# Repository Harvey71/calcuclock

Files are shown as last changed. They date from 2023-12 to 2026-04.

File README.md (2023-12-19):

# CalcuClock

Inspired by a commercial product (Albertclock), I always wanted to create a similar project. The idea is, that the time is displayed as two simple math expressions, which the user has to solve in order to read the clock.
Take it as an educational mean or just a geek toy. ;-)

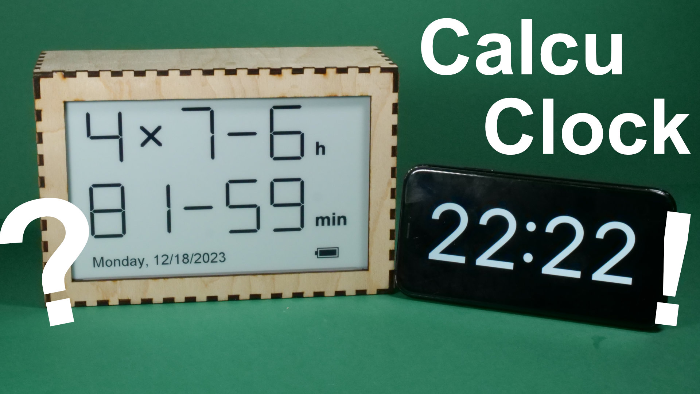
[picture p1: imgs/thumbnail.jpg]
CalcuClock


I used a Firebeetle ESP32 microcontroller board, which has a very low deep sleep current, a Wireshare 7.5 inch ePaper display and a DS3231 real time clock module. The clock is powered by a 10,000 mAh recharchable LiPo-battery, which hopefully will provide a very long duration before recharging, so you can place it anywhere you want (desk, shelf, wall) without a cable attached.

You can easily set up time and time zone by using a standard smartphone and WiFi.

You can watch the clock in action and how I made it at https://youtu.be/ywXnWx0vjIA.

## Hardware

### Part List

| Part | Link |
|---|---|
| Firebeetle ESP32 Microcontroller Board | https://www.dfrobot.com/product-1590.html |
| Waveshare E-Paper Driver HAT | https://www.waveshare.com/product/displays/e-paper/driver-boards/e-paper-driver-hat.htm |
| Waveshare 800×480, 7.5inch E-Ink raw display | https://www.waveshare.com/7.5inch-e-paper.htm |
| Makerfocus 10,000 mAh LiPo Battery | https://www.amazon.de/gp/product/B0953L98RK |
| USB-C power socket | https://www.amazon.de/gp/product/B0C6D2YS1V |
| Push Button Switch | https://www.amazon.de/gp/product/B081TZFZVS |
| DS3231 RTC module | https://www.amazon.de/gp/product/B07GZHTKCS |
| 2 x 1 MOhm resistor | |
| 1 x 100 nF capacitor | |
| 3 mm plywood | |
| Breadboard, screws, cables, spacer, pin header, etc | | 

### Microcontroller

The microcontroller board comes with a voltage divider for measuring battery voltage, but two connections have to
be bridged in order to make this divider work:

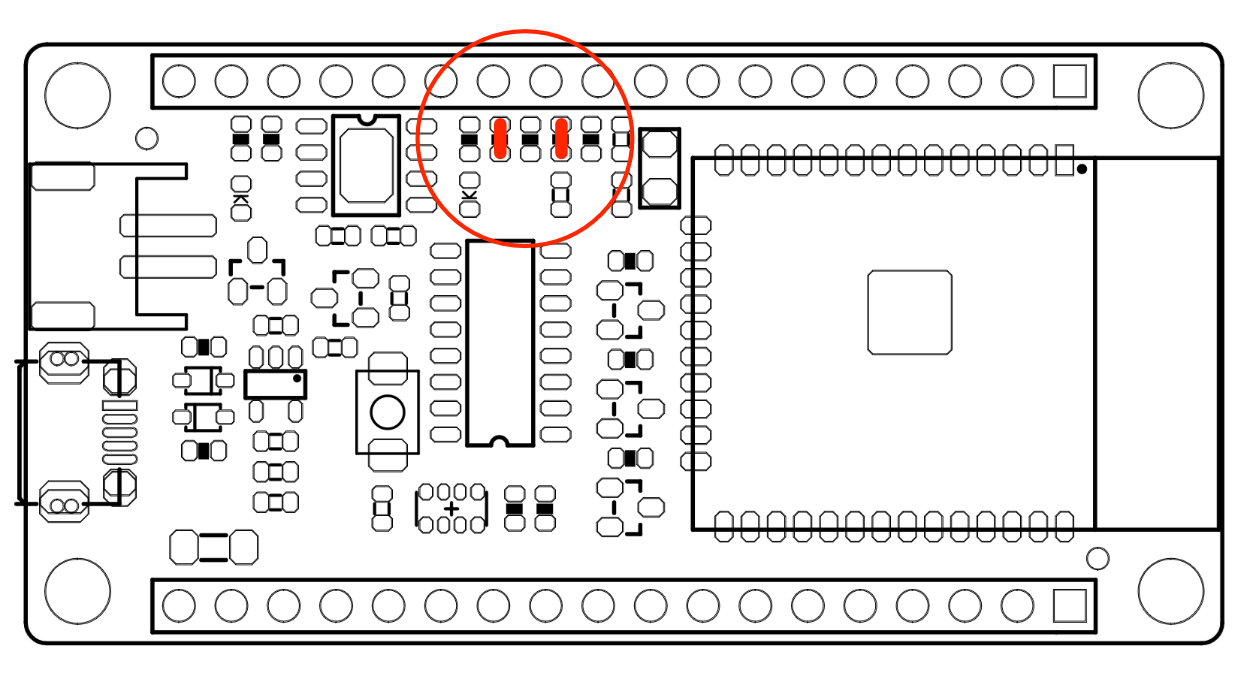
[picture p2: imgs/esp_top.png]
Firebeetle top


You could use a USB cable extension to make the USB connection accessible from outside the box, but I wanted to use a
USB-C power socket, so I had to connect it to the board directly:

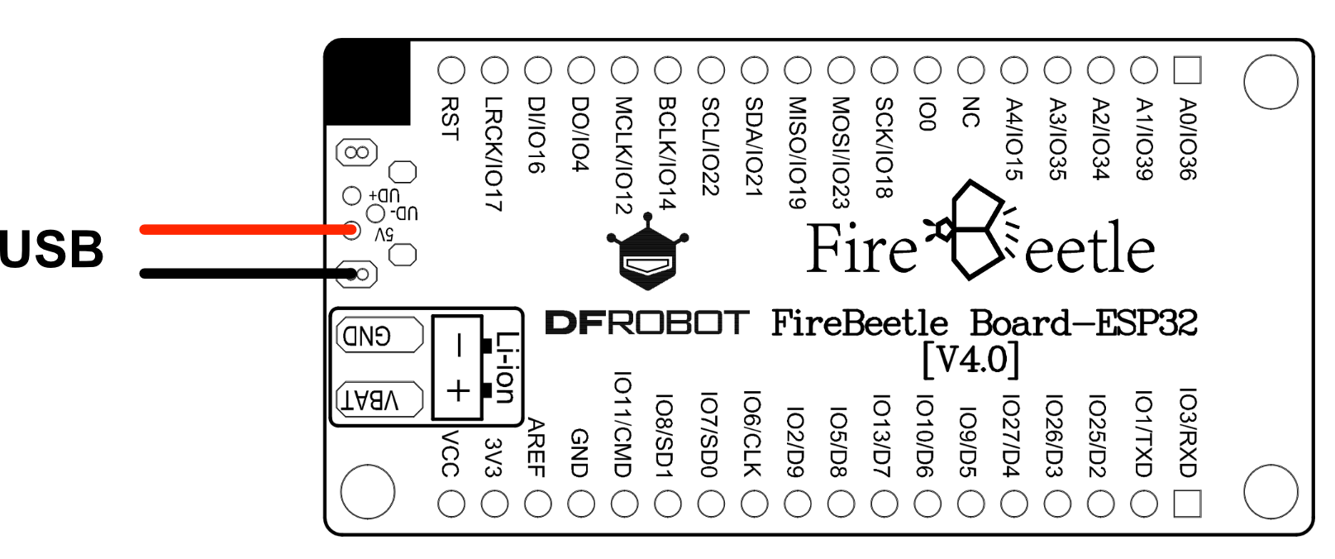
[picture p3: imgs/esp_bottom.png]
Firebeetle bottom


### Bread board

Unfortunately, the Firebeetle does not come with a USB voltage sensor. So I had to install an extra voltage divider on
my own with two 1 MOhm resistors. I used a breadboard and pin headers to connect the microcontroller, the RTC module and
the reset button. I soldered the E-Paper driver cable directly to the board:

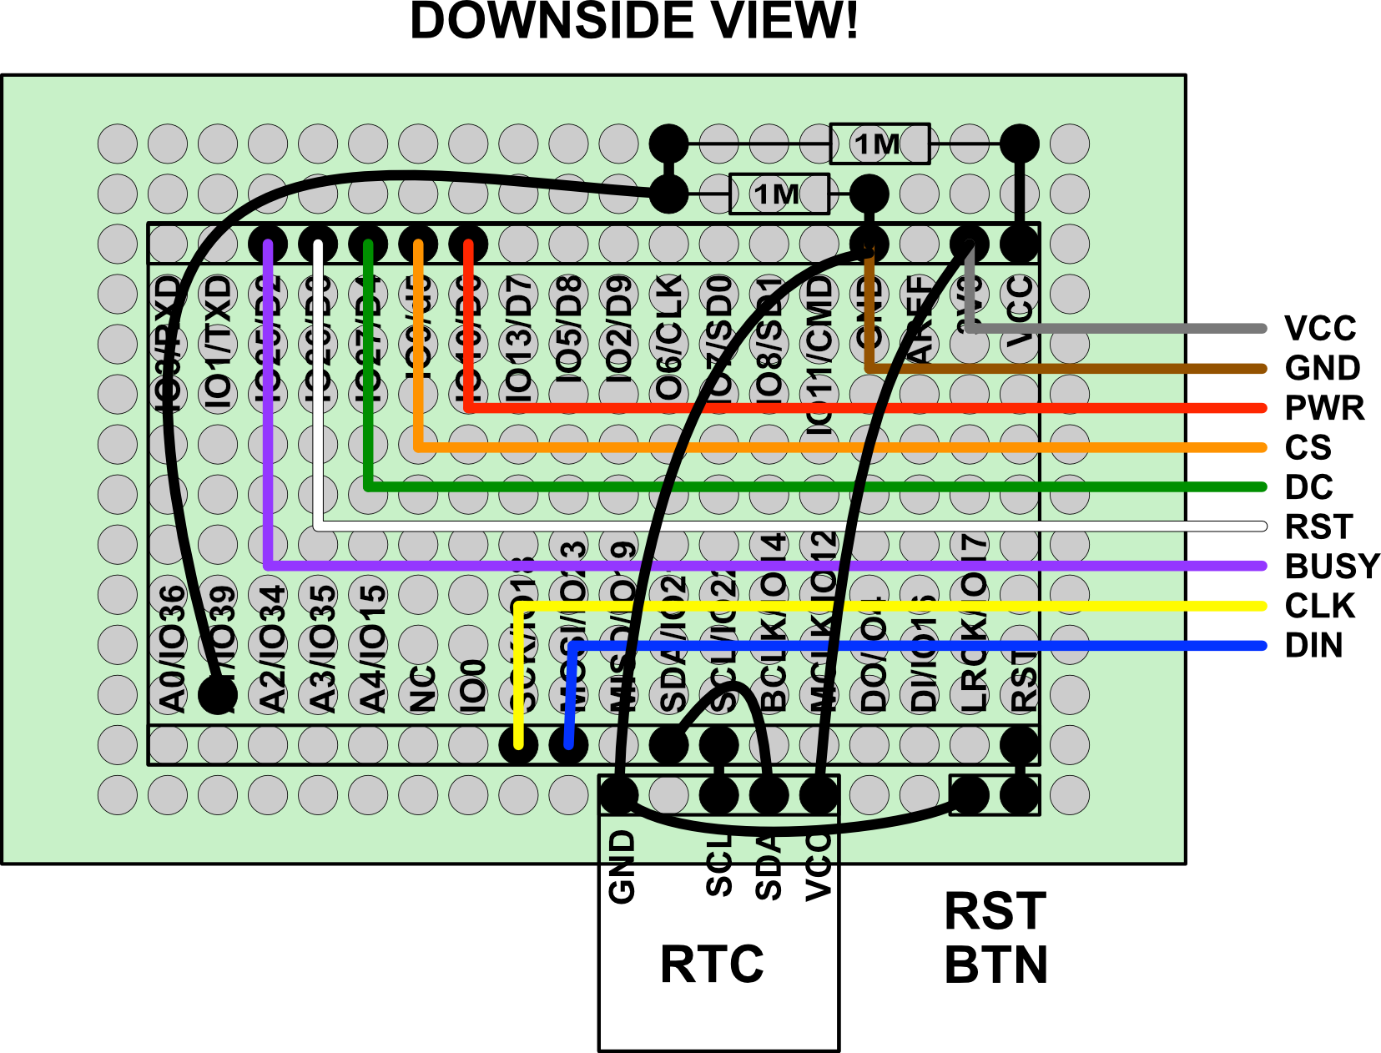
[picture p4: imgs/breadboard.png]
Breadboard


### RTC module

I had some troubles with the accuracy of the RTC module. A 100nF capacitor between GND and VCC soldered directly to 
the module helped.

### Casing

For the casing you would need a laser cutter. I used a Snapmaker A350T with 40W laser module and standard settings.
You can find the cutting blueprints as SVG files in the [box](box) directory.

box1
box2

## Software

Just install a micropython firmware on the ESP32 and copy all the files from [code](code) to the microcontroller file system.
I recommend using Thonny (https://thonny.org/) for that. Be patient, this may take a while.

The digits are pre-rendered and the math expressions are pre-calculated. You can easily change either of them using the 
Python scripts provided in the [tools](tools) directory.

## Usage

After assembling the clock (see video for that), you have to set the time, time zone and date format. For that,
the ESP32 opens a Wifi network (SID "calcuclock") and provides a simple web interface on http://192.168.4.1.
The WiFi password is generated randomly at first activation of the clock.

To make setup easy for a user with a smartphone, the clock displays two QR codes on the e-paper display - one for the 
WiFi settings and one for the URL. Just scan and execute the QR codes as displayed on the e-paper and the setup
interface will appear on your phone. Choose your settings and press "Synchronize". The current date and time will be
read automatically from your phone and sent to the clock. After that the clock will switch to regular work mode and
displays the time as math equations. The display will be updated every minute.

If you want to change the settings later on, just press the reset button on the back of the clock and it will go to
setup mode again.

## Limitations

While the time zone selection should be sufficient, I only implemented two date formats: English and German. Please feel
free to add further. Just add them to the dt_formats object in the [code/clock.py](code/clock.py) file.

I also implemented a 24h mode only. If you really want a 12h AM/PM display, you would have to modify the code.

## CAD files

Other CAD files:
box/box.dxf
box/box2.dxf

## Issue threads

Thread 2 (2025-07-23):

Bridges at microcontroller

Ra1080, 2025-07-23:
You wrote, that two connections at the microcontroller board have to be bridged in order to make the voltage divider work. As far as I could see, the bridges in the linked video differ from the ones marked in your description. Which of them is correct? Thank you for your answer.

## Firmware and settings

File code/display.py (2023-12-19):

import machine
import time
from lib.writer import writer
import framebuf
import arial_40
from array import array

class DisplayFrameBuffer(framebuf.FrameBuffer):

    def __init__(self, buf, width, height, *args, **kwargs):
        self.width = width
        self.height = height
        super().__init__(buf, width, height, *args, **kwargs)
        
class Display:

    def __init__(self):
        self.width = 800
        self.height = 480
        self.buf = bytearray(self.width * self.height // 8)
        self.fb = DisplayFrameBuffer(self.buf, self.width, self.height, framebuf.MONO_HLSB)
        self.writer = writer.Writer(self.fb, arial_40)
        self.busy_pin = machine.Pin(25, machine.Pin.IN)
        self.rst_pin = machine.Pin(26, machine.Pin.OUT)
        self.dc_pin = machine.Pin(27, machine.Pin.OUT)
        self.cs_pin = machine.Pin(9, machine.Pin.OUT)
        self.pwr_pin = machine.Pin(10, machine.Pin.OUT)
        self.clk_pin = machine.Pin(18, machine.Pin.OUT)
        self.din_pin = machine.Pin(23, machine.Pin.OUT)
        self.spi = machine.SPI(2, baudrate=2_000_000, sck=self.clk_pin, mosi=self.din_pin)
        self.char_width = 96
        self.char_height = 150
        self.char_spacing = 120 - self.char_width
        self.on()
        self.reset()
        self.init()

    def on(self):
        self.pwr_pin.on()

    def off(self):
        time.sleep_ms(20)
        self.pwr_pin.off()

    def reset(self):
        self.rst_pin.off()
        time.sleep_ms(4)
        self.rst_pin.on()
        time.sleep_ms(200)
    
    def wait(self, sleep_before=None):
        if sleep_before:
            time.sleep_ms(sleep_before)
        while not self.busy_pin.value():
            time.sleep_ms(20)

    def command(self, command, data=None):
        self.cs_pin.off()
        self.dc_pin.off()
        self.spi.write(command)
        if data:
            self.dc_pin.on()
            self.spi.write(data)
        self.cs_pin.on()

    def init(self):
        self.command(b'\x01', b'\x07\x07\x3f\x3f')
        self.command(b'\x04')
        self.wait(100)
        self.command(b'\x00', b'\x1f')
        self.command(b'\x61', b'\x03\x20\x01\xe0')
        self.command(b'\x15', b'\x00')
        self.command(b'\x50', b'\x10\x07')
        self.command(b'\x60', b'\x22')
        self.wait()

    def show(self):
        self.command(b'\x13', self.buf)
        self.command(b'\x12')
        self.wait(100)

    def sleep(self):
        self.command(b'\x02')
        self.wait()
        self.command(b'0x07', b'0xa5')
        time.sleep_ms(2000)
        self.off()
        self.fb = None
        self.buf = None

    def text(self, s, x, y, center=False):
        w = self.writer.stringlen(s)
        if center:
            x -= w // 2
        self.writer.set_textpos(self.fb, y, x)
        self.writer.printstring(s)
    
    def big_text(self, line, x, y):
        line = line.replace('*', 'x')
        line = line.replace('/', 'd')
        for c in line:
            with open(c + '.buf', 'rb') as f:
                char_buf = bytearray(f.read())
            char_fb = framebuf.FrameBuffer(char_buf, self.char_width, self.char_height, framebuf.MONO_HLSB)
            self.fb.blit(char_fb, x, y)
            x += self.char_width + self.char_spacing
    
    @micropython.native
    def qr(self, s, left, top, bs = 4):
        from lib.uqr.uQR import QRCode
        qr = QRCode()
        qr.add_data(s, 0)
        matrix = qr.get_matrix()
        for y in range(len(matrix)):
            for x in range(len(matrix[y])):
                col = 1 if matrix[y][x] else 0
                x1 = left + x * bs
                y1 = top + y * bs
                x2 = x1 + bs - 1
                y2 = y1 + bs - 1 
                self.fb.fill_rect(x1, y1, x2, y2, col)
    
    def draw_battery(self, x, y, cap, loading, drained, bs=1):
        self.fb.fill_rect(x - 10 * bs, y - 5 * bs, 1 * bs, 10 * bs, 1)
        self.fb.fill_rect(x + 9 * bs, y - 5 * bs, 1 * bs, 10 * bs, 1)
        self.fb.fill_rect(x - 10 * bs, y - 5 * bs, 20 * bs, 1 * bs, 1)
        self.fb.fill_rect(x - 10 * bs, y + 4 * bs, 20 * bs, 1 * bs, 1)
        self.fb.fill_rect(x - 12 * bs, y - 2 * bs, 2 * bs, 4 * bs, 1)
        if loading:
            self.fb.fill_rect(x - 2 * bs, y - 3 * bs, 4 * bs, 6 * bs, 1)
            self.fb.fill_rect(x - 3 * bs, y - 2 * bs, 1 * bs, 4 * bs, 1)
            self.fb.fill_rect(x + 2 * bs, y - 2 * bs, 3 * bs, 1 * bs, 1)
            self.fb.fill_rect(x + 2 * bs, y + 1 * bs, 3 * bs, 1 * bs, 1)
            self.fb.fill_rect(x - 6 * bs, y - 1 * bs, 3 * bs, 2 * bs, 1)
        elif drained:
            self.fb.poly(x - 4 * bs, y - 3 * bs, array('h', [
                0 * bs, 6 * bs,
                6 * bs, 0 * bs,
                8 * bs, 0 * bs,
                2 * bs, 6 * bs,
                0 * bs, 6 * bs
            ]), 1, True)
        else:
            o = round((100 - cap) / 100 * 16 * bs)
            self.fb.fill_rect(x - 8 * bs + o, y - 3 * bs, 16 * bs - o, 6 * bs, 1)

                   
def test():
    display = Display()
    display.text('Hello world', 10, 10)
    display.big_text('1+2*3', 10, 60)
    display.qr('http://www.heise.de', 10, 300)
    display.show()
    display.sleep()

def clear():
    display = Display()
    display.show()
    display.sleep()
    

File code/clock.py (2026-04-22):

import machine
import time
import random
import os

dt_formats = {
    'English': {
        'weekdays' :['Monday', 'Tuesday', 'Wednesday', 'Thursday', 'Friday', 'Saturday', 'Sunday'],
        'format': '%w, %mm/%d/%y',
    },
    'German': {
        'weekdays' :['Montag', 'Dienstag', 'Mittwoch', 'Donnerstag', 'Freitag', 'Samstag', 'Sonntag'],
        'format': '%w, %d.%mm.%y',
    },
}

EPOCH_OFFSET = 946684800

class Clock:
    
    def __init__(self, df_name = None, tz_name = None):
        self.i2c = machine.SoftI2C(sda=machine.Pin(21), scl=machine.Pin(22))
        self.tz_data = None
        self.dt_format = None
        self.weekdays = None
        if tz_name:
            try:
                tz_module = __import__('_zones/' + tz_name)
                self.tz_data = tz_module.tz_data
            except:
                self.tz_data = None
        if df_name:
            self.dt_format = dt_formats.get(df_name, {}).get('format')
            self.weekdays = dt_formats.get(df_name, {}).get('weekdays')
        self.choices = os.stat('expressions.txt')[6] // (6 * 60)
        
    def read(self, offset=0):
        data = self.i2c.readfrom_mem(104, 0, 7)
        def bcd(pos, mask=0xff):
            d = data[pos] & mask
            return (d & 0x0f) + ((d >> 4) * 10)
        s = bcd(0)
        m = bcd(1)
        h = bcd(2, 0x3f)
        w = bcd(3)
        d = bcd(4)
        mm = bcd(5, 0x7f)
        y = bcd(6) + 2000 + (data[5] >> 7) * 100
        t = time.mktime((y, mm, d, h, m, s, w, 0)) + offset
        # adjust by timezone
        if self.tz_data:
            offset = 0
            for k, v in sorted(self.tz_data):
                if t + EPOCH_OFFSET >= k:
                    offset = v
            t += offset
        return time.gmtime(t)
    
    def get_strings(self, offset=0):
        y, mm, d, h, m, s, w, dd, *_ = self.read(offset)
        with open('expressions.txt') as f:
            f.seek((h * self.choices + random.randint(0, self.choices - 1)) * 6)
            hs = f.read(5)
            f.seek((m * self.choices + random.randint(0, self.choices - 1)) * 6)
            ms = f.read(5)
        hs += 'h'
        ms += 'm'
        ds = ''
        if self.dt_format and self.weekdays:
            ds = self.dt_format
            ds = ds.replace('%d', f'{d:02}')
            ds = ds.replace('%mm', f'{mm:02}')
            ds = ds.replace('%y', f'{y:04}')
            ds = ds.replace('%w', self.weekdays[w])
        return hs, ms, ds
        
    def set_from_epoch(self, epoch):
        data = bytearray(7)
        def bcd(pos, d, bits=0x00):
            b = (d % 10) + (d // 10) * 16 | bits
            data[pos] = b
        gmt = time.gmtime((epoch - 946684800000) // 1000)
        y = gmt[0] - 2000
        y = max(0, y)
        y = min(199, y)
        mm = gmt[1]
        d = gmt[2]
        h = gmt[3]
        m = gmt[4]
        s = gmt[5]
        w = gmt[6] # 0 = Monday
        century = 0x00
        if y > 100:
            y -= 100
            century = 0x80
        bcd(0, s)
        bcd(1, m)
        bcd(2, h)
        bcd(3, w)
        bcd(4, d)
        bcd(5, mm, century)
        bcd(6, y)
        self.i2c.writeto_mem(104, 0, data)
        
def test():
    from time import sleep_ms
    c = Clock('Europe/Berlin')
    c.set_from_epoch(1702383162465)
    for _ in range(10):
        print(c.read())
        sleep_ms(990)

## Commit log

2024-06-16 fix daylight saving time adjustment
    [clock.py]
2026-05-29 add dxf files for box parts
    [box.dxf, box2.dxf]
